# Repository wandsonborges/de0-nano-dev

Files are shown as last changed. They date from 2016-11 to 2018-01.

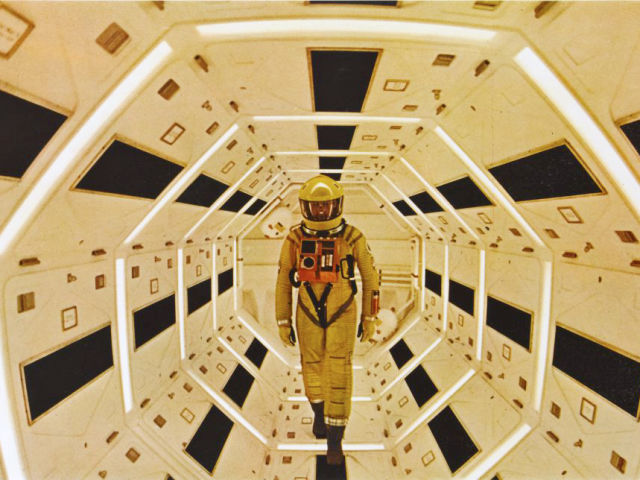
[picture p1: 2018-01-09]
src/homography/cpp/2001.jpeg

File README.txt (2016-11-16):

Step-by-step
1) Generate Qsys files.
1.1) Open cycloneV_soc.qsys and GENERATE

2)Run Analysis and Sinthesys in Quartus.

3) TCL script -> sdram pin assignment

4) Full compile in Quartus

5) Create header files:
5.1) use nios2 command shell para carregar sopc-create-header-files 
5.2) sopc-create-header-files cycloneV_soc.sopcinfo --output-dir qsys_headers/

6) Make na aplicacao linux_app

7) Passe o binario para a placa, via sd-card ou outra coisa

8) entre na placa com m linux carregado e execute

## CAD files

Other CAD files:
output_files/framewriter.stp
src/lwir_ul0304/stp_addVector_resume.stp
output_files/nuc_st.stp
src/lwir_ul0304/stp_addVector2.stp
output_files/lwir_avalon.stp
src/lwir_ul0304/stp_lwir.stp
output_files/bridge_triple_buffer.stp
src/lwir_ul0304/stp_lwir_mem.stp
output_files/homog_bridge.stp
src/lwir_ul0304/stp_addVector.stp
output_files/homog.stp
output_files/trippleBuffer.stp
output_files/bridge_stp.stp
output_files/homog_stp.stp
AutoCorrelacao/src/work/avaloncontrolslavedecoder/arch.psm
AutoCorrelacao/src/work/avaloncontrolslavedecoder/bhv.psm
AutoCorrelacao/src/work/lupa_library/_vhdl.psm
AutoCorrelacao/src/work/lupa_library/body.psm

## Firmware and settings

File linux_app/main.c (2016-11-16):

#include <stdio.h>
#include <unistd.h>
#include <fcntl.h>
#include <sys/mman.h>
#include "hwlib.h"
#include "../qsys_headers/hps_0.h"


#define LW_AXI_BASE 0xFF200000 //ARM LW ADDR BASE
#define LW_AXI_SPAN 0x00200000 //2 MB SIZE

#define H2F_AXI_BASE 0xC0000000
#define H2F_AXI_SPAN 0x80000


void* h2f_axi_base;
void* virtual_base;
void* reserved_base;
void* led_addr;
void* sw_addr;

int fd;
int switches;

uint32_t mem_value;
uint32_t axi_value;

int i;

int main (){
  fd=open("/dev/mem",(O_RDWR|O_SYNC));


  //Creating pointer do LWAXI bus
  virtual_base = mmap(NULL,LW_AXI_SPAN,(PROT_READ|PROT_WRITE),MAP_SHARED,fd,LW_AXI_BASE);
  h2f_axi_base = mmap(NULL,H2F_AXI_SPAN,(PROT_READ|PROT_WRITE),MAP_SHARED,fd,H2F_AXI_BASE);

  sw_addr = h2f_axi_base + SW_BASE; //defined in hps_0.h
  led_addr = h2f_axi_base + LED_BASE; //defined in hps_0.h

  
  while(1){
    switches=*(uint32_t *)sw_addr;
    *(uint32_t *)led_addr=switches;
    usleep(1000000);
    printf("SW_value :%u\n",switches);
  }

return 0;
}

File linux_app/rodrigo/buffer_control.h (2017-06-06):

#include <stdio.h>
#include <stdlib.h>
#include <sys/mman.h>
#include <unistd.h>
#include <fcntl.h>


#define FRAME_ADDR 0xFF210000
#define FRAME_SPAN 0x10

#define REG_ADDR_OFFSET 0
#define REG_REQBUFFER_OFFSET 1 

void* frame_base;

void requestBuffer(void* mem)
{
	*((int*)(mem) + REG_REQBUFFER_OFFSET) = 1;	
}

void freeBuffer(void* mem)
{
	*((int*)(mem) + REG_REQBUFFER_OFFSET) = 0;
}

int getBufferAddr(void* mem)
{
	int buffer_addr = *(int*) (mem + REG_ADDR_OFFSET);
	return buffer_addr;
}

int checkBufferStatus(void* mem) //1 - livre ; 0 - busy
{
	int status = *((int*)(mem) + REG_REQBUFFER_OFFSET);
	if (status) printf("***Buffer Status : BUFFER FREE\n");
	else printf("***Buffer Status: BUFFER LOCKED\n");
	return status;
}

int getBufferAddrControl(void* mem)
{
	int buf_addr;

	requestBuffer(mem);
	buf_addr = getBufferAddr(mem);
	freeBuffer(mem);
	
}
	

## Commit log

2016-11-16 fpga2sdram bridge workging; fpga 2 sdram write working; lw bridge working; linux booting
    [c5_pin_model_dump.txt, hps_sdram_p0_summary.csv]
2017-03-03 Autocorrelation iterfacing to Avalon bus working
    [_vhdl.psm, arch.psm, bhv.psm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]
2017-03-15 Adicao do modulo que faz bridge avalon st source -> avalon memory mapped master
2017-03-16 1a versao Frame writer funcionando
2017-03-22 Core que recebe imagens do modulo d5m terasic
2017-03-23 Teste do sensor d5m
2017-03-25 Camera 5Mpx funcionando! 2.5 fps
    [bridge_stp.stp]
2017-03-29 adding multi thread image feeder
2017-03-29 adicionado parte de socket no feeder
2017-03-30 device's process that streams up images working
2017-03-31 Timing da camera corrigido.
2017-04-01 Subindo arquivos frame buffer com slave
2017-05-01 slave da bridge ok~
    [bridge_stp.stp]
2017-05-01 buffer_pinpong corrigido
    [bridge_stp.stp]
2017-05-04 Controlador de double buffer testado e funcionando
    [bridge_stp.stp]
2017-06-06 Consertado problema slave bridge: Problema era clock do slave. Criado emulador de v200 server em linux_app/rodrigo
    [buffer_control.h]
2017-06-07 Bloco de homografia DMA adicionado
2017-06-09 Homografia vazao melhorada
    [homog_bridge.stp]
2017-06-09 homog melhorada
    [bridge_stp.stp, homog_bridge.stp, homog_stp.stp]
2017-10-28 addVector funcionando com passagem de ponteiros parametrizavel
2017-11-08 atualizando driver
2018-06-10 Configuracao de registros atualizada e testada
2018-06-11 SOC funcionando para imagens VGA e kernel 3x3. Comparacao com SW feita com sucesso, tendo resultados mais rapidos
2019-02-25 2 canais com nuc funcionando ao mesmo tempo
    [stp_addVector.stp, stp_addVector2.stp, stp_lwir.stp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]
2019-02-28 homografia funcionandogit add hps_isw_handoff/*! sem burst
    [homog.stp]
2019-03-20 tripple buffer testado e funcionando. Escrevendo padrao do bridge! Alterar para imagem!
2019-03-22 subindo arquivos esquecidos no ultimo commit
    [bridge_stp.stp, homog.stp, homog_bridge.stp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]
2019-03-27 nuc com avalon st testado e funcionando com um canal
    [bridge_triple_buffer.stp, lwir_avalon.stp, nuc_st.stp]
2019-03-28 2 canais com nuc st testado e funcionando!
    [nuc_st.stp]
2021-01-15 funcionando sensor vga 60 fps
2021-01-15 subindo output files
    [framewriter.stp]
